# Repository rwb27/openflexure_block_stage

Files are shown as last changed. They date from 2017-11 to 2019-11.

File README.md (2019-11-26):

# This repository has moved!
Please head to our new home on Gitlab: https://gitlab.com/openflexure/openflexure-block-stage/

# OpenFlexure Block Stage
A 3D Printable high-precision 3 axis translation stage.

This project is a 3D printable design that enables very fine (sub-micron) mechanical positioning of a small moving stage, with surprisingly good mechanical stability.  It follows on from the [OpenFlexure Microscope](https://github.com/rwb27/openflexure_microscope) which is discussed in a [paper in Review of Scientific Instruments](http://dx.doi.org/10.1063/1.4941068) (open access).  Currently, it's designed to function as a more-or-less drop in replacement for fibre alignment stages available from various scientific suppliers, but the project aims to be useful to electrophysiologists, nanotechnology folk, and many more.

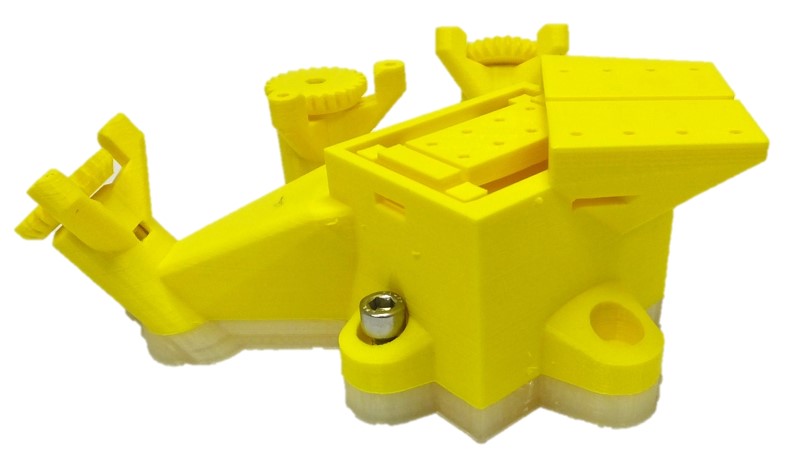
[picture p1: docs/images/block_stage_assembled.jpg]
An assembled block stage


## Kits and License
This project is open-source and is released under the CERN open hardware license.  You can buy a kit of the openflexure microscope from [WaterScope](http://www.waterscope.org/).  Currently, only microscope kits are listed, but if you send an email it should be possible to get this stage as a custom order.

## Printing/building it yourself
To build the stage, download the [STL files](./stl/) and print them.  Don't just print everything from the STL folder,
as currently it contains some parts that must be printed multiple times, and other parts
that are redundant.  The readme in that folder should point you in the right direction.

Instructions for this stage are currently work-in-progress.  However, the assembly of the actuators is exactly the same as for the OpenFlexure Microscope, which has [online instructions](http://rwb27.github.io/openflexure_microscope/docubricks/current_master_version.html).  Instead of separate feet, this design has a single baseplate, which is just glued onto the bottom of the main body of the stage.  Once the actuators are assembled as per those instructions, you just need to mount whatever you're going to translate onto the stage using the 8 M3 "self tapping" holes (tapping them with a tap wrench can help get the screw started).  There's a "moving stage" part that makes it a drop-in replacement for the ThorLabs/Newport XYZ fibre alignment stages, if that is of interest.

## Get Involved
It's already useful if you get involved by raising [issues](https://github.com/rwb27/openflexure_block_stage/issues) if there are things that aren't clear, and anyone who might want to help write better instructions would be very welcome.  Ideally it should be in DocuBricks format, but Markdown/Wiki is a lot better than nothing.  Improvements to the code, or even just sharing parameters you used (if you customised it) and how well it worked would be great.  If you've built one, please post a photo and any comments - you could use the wiki, or [raise an issue tagged "build report"](https://github.com/rwb27/openflexure_block_stage/issues/new?labels=build%20report).

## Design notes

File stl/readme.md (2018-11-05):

# OpenFlexure Block Stage STL Files
This folder is for built STL files.  It's possible I should have excluded these from the repo, as they are build products - but it's often handy to have them here.  *Please don't just print this folder* as there is no guarantee that one of each is the right combination of things to print!

To make one stage, you need:
* 1x stage body (``main_body.stl`` - or optionally the one with ``no_fixed_platform`` or ``long_z_travel``.  Use the ``betweenholes`` version if you want the stage to bolt down to a breadboard with the beam path between two lines of holes (the default is to align it so the beam runs directly along a line of holes).)
* 1x base (``base.stl``) - check this matches up with the top part you've chosen (the top of this should match the bottom of the stage - they just glue together).
* 3x ``large_gear.stl`` to actuate the three axes
* 1x moving platform (``moving_platform.stl``) if you would like drop-in compatibility with standard fibre alignment stages.

If you are planning to motorise the stage with 28BYJ-48 stepper motors, you'll also need:
* 3x ``small_gear.stl``

In addition to the printed parts, you also need:
* 3x Viton o-rings
* 3x M3 full nut, preferably brass
* 3x M3 hexagon head bolts, 25mm long
* 3x M3 washer

If you are building a motorised stage, you also need
* 3x 28BYJ-48 stepper motors
* 6x M4x6mm screws (I use button head with a hex socket)

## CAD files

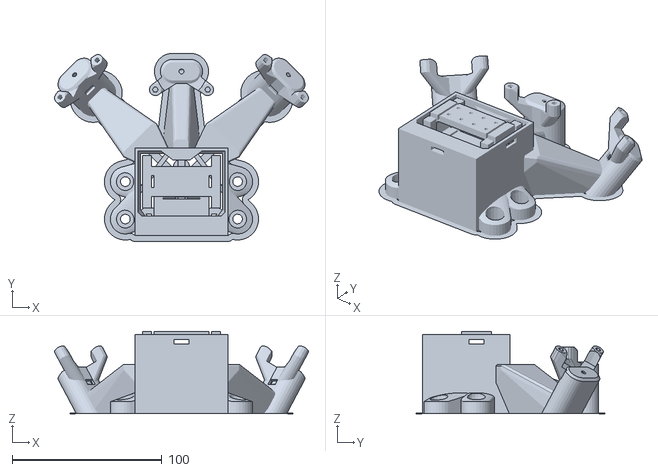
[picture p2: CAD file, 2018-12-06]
stl/main_body_brim.stl
169.7 x 125.8 x 55.0

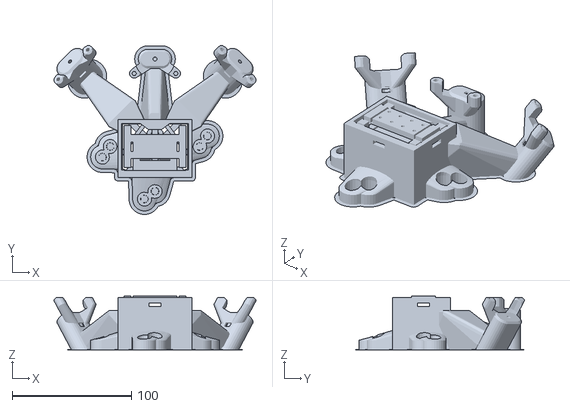
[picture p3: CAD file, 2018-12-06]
stl/main_body_3mmbrim.stl
169.7 x 141.8 x 45.0

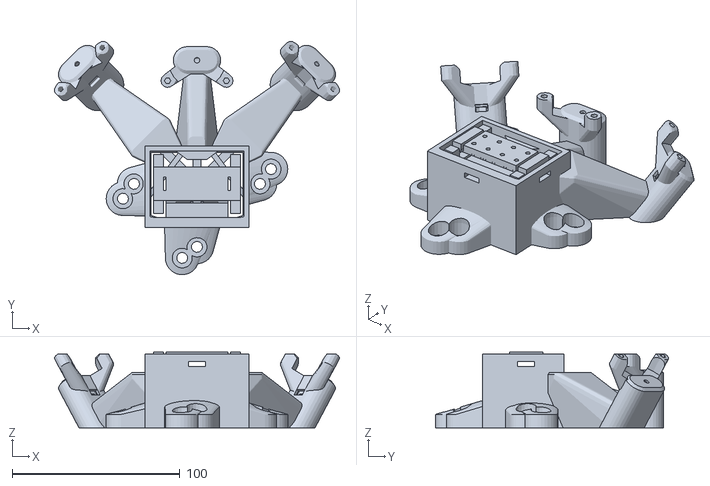
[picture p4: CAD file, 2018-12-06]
stl/main_body.stl
169.7 x 138.8 x 45.0

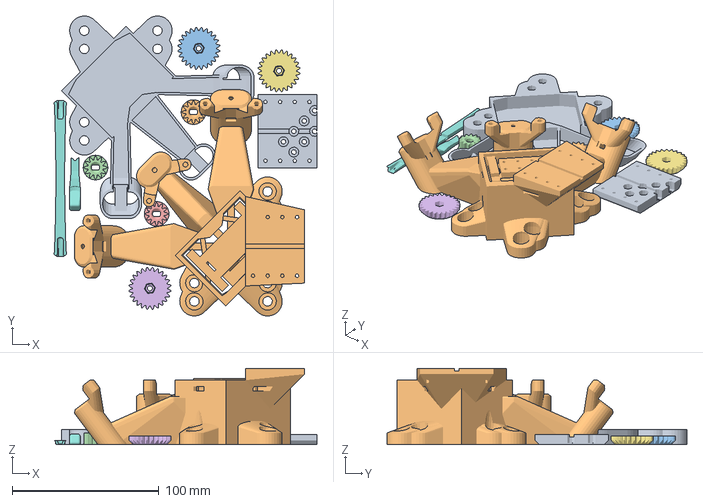
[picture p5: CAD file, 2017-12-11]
stl/1_fs_complete_betweenholes.curaproject.3mf
178.9 x 204.3 x 52.0 mm

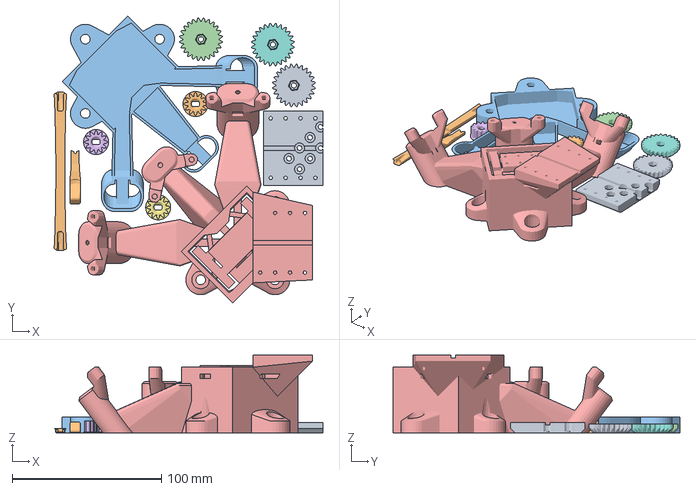
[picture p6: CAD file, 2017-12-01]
stl/1_fs_complete_aligned.3mf
180.3 x 192.6 x 52.0 mm

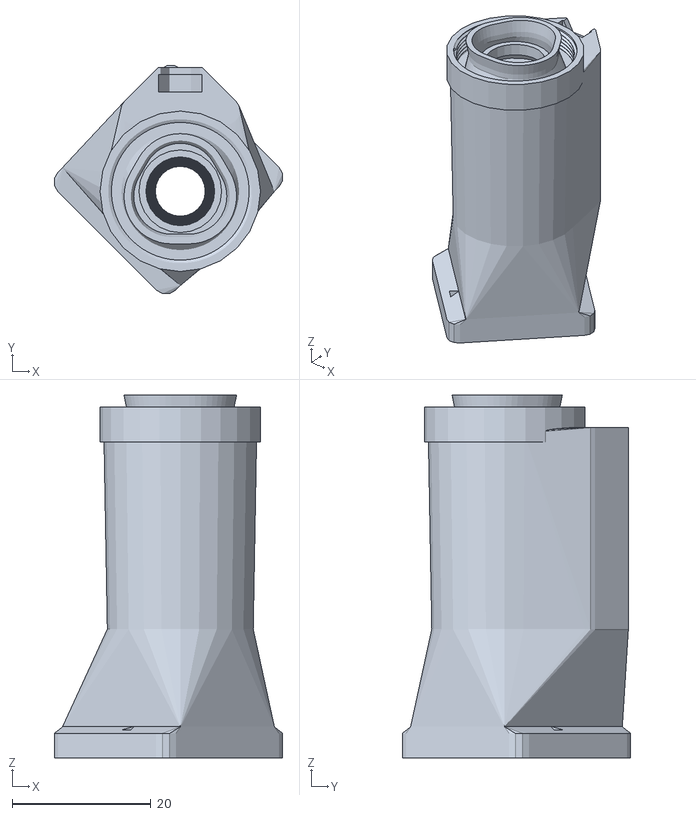
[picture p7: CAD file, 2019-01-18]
openscad/accessories/optics_module_rms_f50d13_infiniteconjugates.stl
32.9 x 32.9 x 52.3

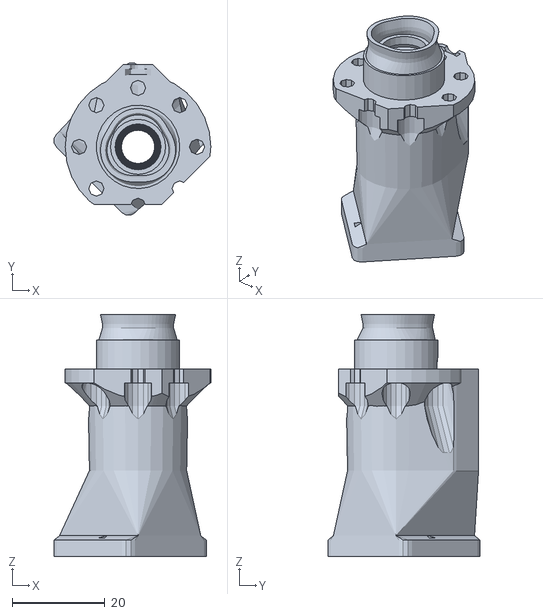
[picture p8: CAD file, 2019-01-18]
stl/accessories/microscope_module_infiniteconjugates.stl
33.9 x 32.9 x 52.3

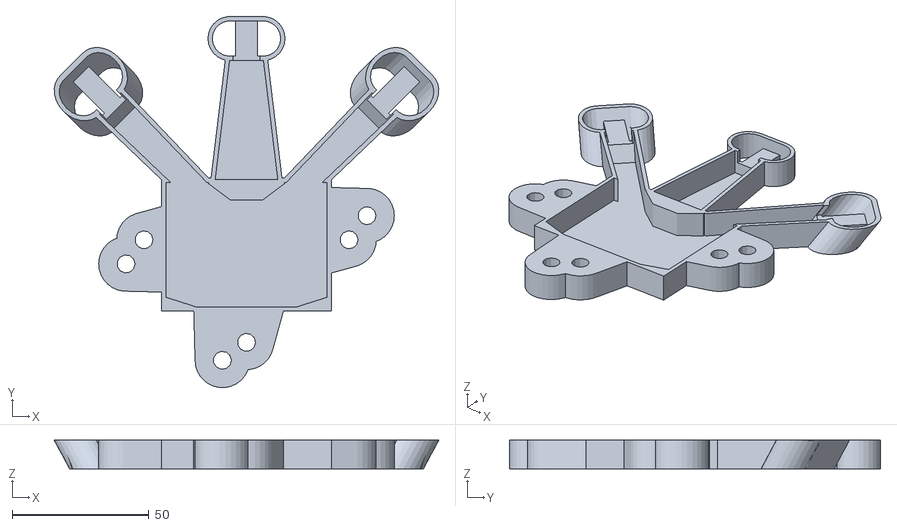
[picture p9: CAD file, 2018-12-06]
stl/base_lugsatsides.stl
140.6 x 135.7 x 10.5

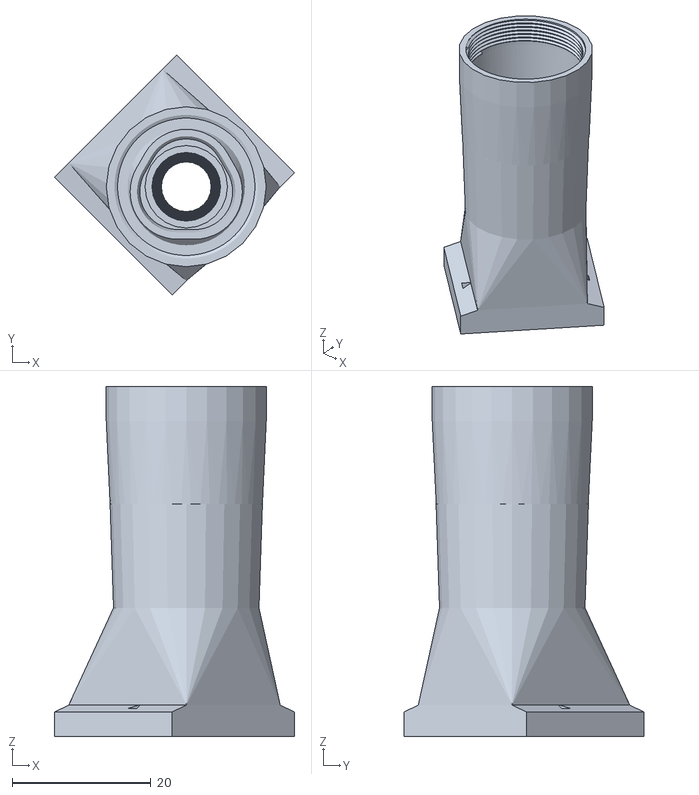
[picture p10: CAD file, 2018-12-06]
openscad/accessories/optics_module_rms_f50d13_nodovetail.stl
34.6 x 34.6 x 50.5

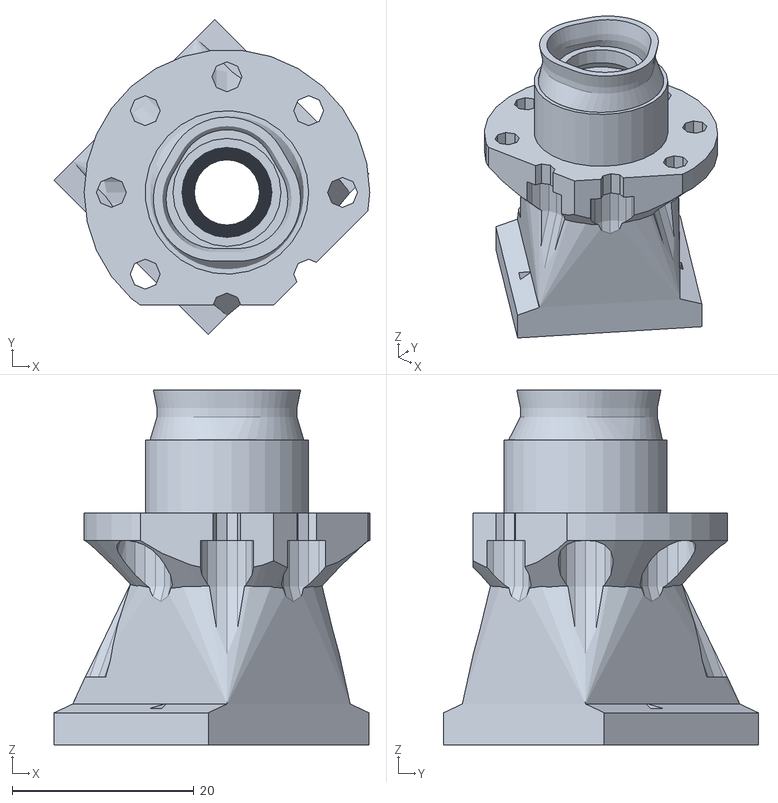
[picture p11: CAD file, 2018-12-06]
stl/accessories/microscope_module_25mm.stl
34.7 x 34.6 x 39.1

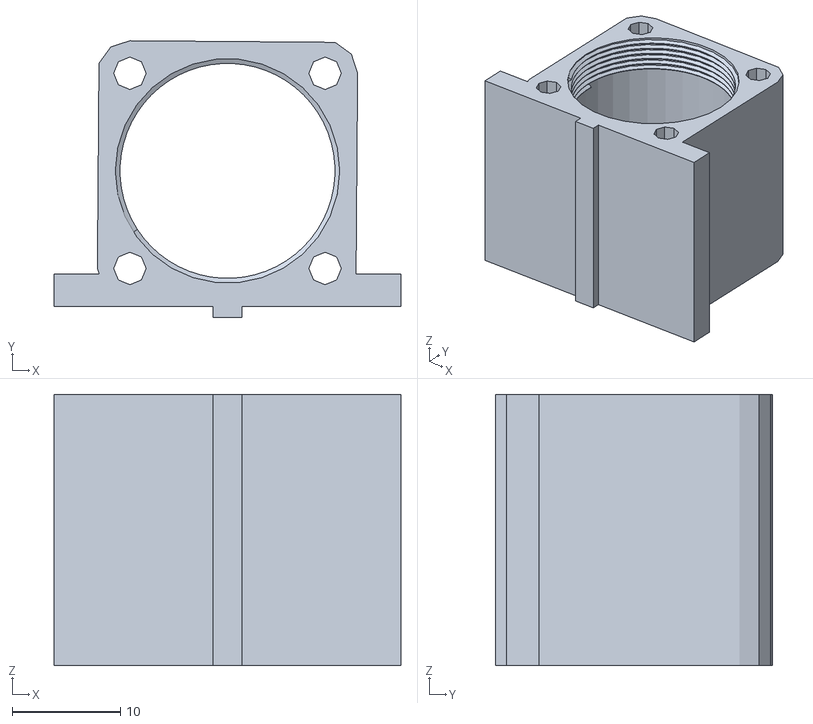
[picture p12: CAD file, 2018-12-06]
stl/accessories/rms_to_stage_25mm.stl
32.0 x 25.5 x 25.0

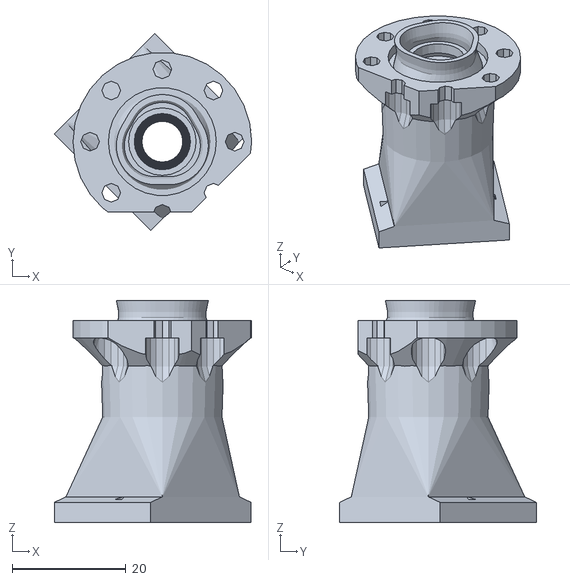
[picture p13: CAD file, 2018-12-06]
stl/accessories/microscope_module_15mm.stl
34.7 x 34.6 x 39.1

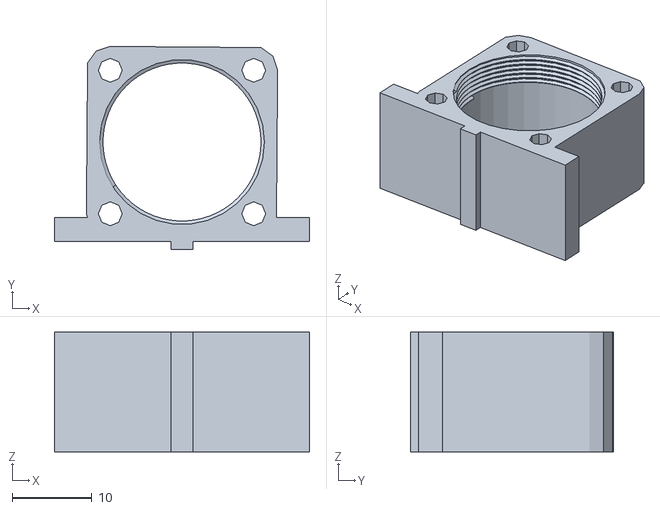
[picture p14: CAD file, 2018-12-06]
stl/accessories/rms_to_stage_15mm.stl
32.0 x 25.5 x 15.0

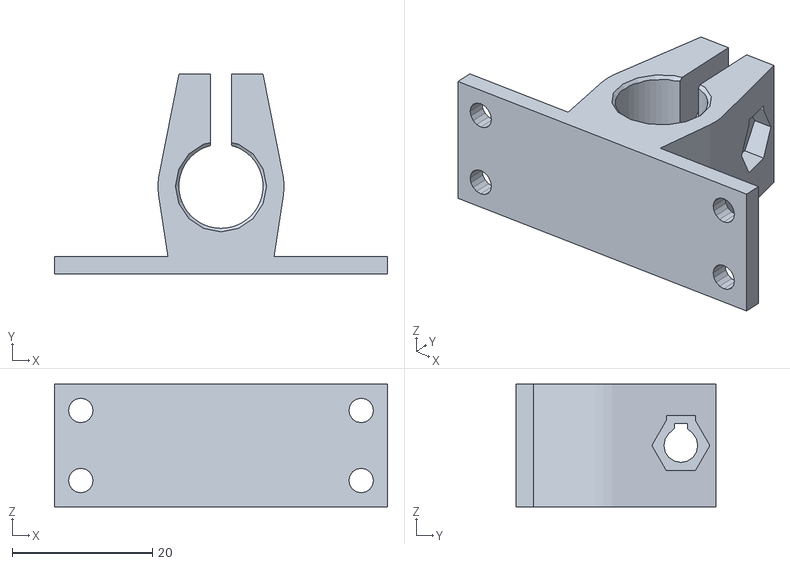
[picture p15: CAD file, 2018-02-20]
stl/accessories/CPS532_to_microblock.stl
47.5 x 28.5 x 17.5

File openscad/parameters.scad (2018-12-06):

/*
  Useful settings/parameters for the OpenFlexure fibre stage
*/
version_numstring = "0.2.1";
stage = [37,20,5]; // dimensions of stage part
beam_height = 75; // height of beam above the table
stage_to_beam_height = 12.5;
stage_height = beam_height - stage_to_beam_height; //bottom of base to top surface of the stage 
 // NB platform_z sets the distance from bottom of the body to top of the stage
 // stage_height determines the thickness of the base.
brim_r = 0;

// Range of travel is lever length * flex_a
xy_lever = 10;
z_lever = 10;

// Mechanical reduction settings
xy_stage_reduction = 30/xy_lever; //ratio of sample motion to lower shelf motion
xy_reduction = 50/xy_lever; //mechanical reduction from screw to sample
z_reduction = 50/z_lever; //mechanical reduction for Z

// Motor lugs
motor_lugs = true;

// fixed platform for fibre launch
fixed_platform = false;

// Mounting holes
breadboard_lugs="diagonal"; //sets the hole pattern for bolting it down.  See the options below.

// Flexure dimensions - good for PLA and ~0.5mm nozzle
zflex = [6, 1.5, 0.75]; //dimensions of flexure
xflex = [5,5.5,5]; //default bounding box of x flexure
xflex_t = 1; //thickness of bendy bit in x
flex_a = 0.1; //angle through which flexures are bent, radians
dz = 0.5; //thickness before a bridge is printable-on

xy_travel = xy_lever * flex_a; //max. travel in X or Y
xy_bottom_travel = xy_travel * xy_stage_reduction; //travel of bottom of XY stage
xy_actuator_pivot_w = 25; //width of the hinge for the actuating lever
actuator_h = 26; //height of actuator columns (~screw length)

pushstick = [5,38,5]; //cross-section of XY "push stick"
pw = pushstick[0]; //because this is used in a lot of places...

wall_t = 1.6;
d=0.05;

// Height of the bridging "shelves" in the XY axis "table" structure
shelf_z1 = xy_lever * xy_stage_reduction;
shelf_z2 = shelf_z1 + xy_lever;

// Z axis geometry
z_travel = z_lever * flex_a; //max. travel in Z
z_stage_base_y = -stage[1]/2-xy_bottom_travel; //position of the flexure edge of the Z stage
z_stage_base_w = stage[0] + 2*zflex[1] - 2*xy_bottom_travel - 2; //width of the flexure edge of the Z stage
z_anchor_bottom_y = z_stage_base_y - z_lever - zflex[1]; // lower Z stage end of the fixed base
z_actuator_pivot_y = stage[1]/2 + zflex[1] + zflex[0] + xy_bottom_travel + wall_t;
z_actuator_pivot_w = 20; //width of the hinge for the Z actuator lever
z_pushstick_z = shelf_z1 - pw - 2.5; // height of the Z pushstick

// Mounting stuff
// By default, place 3 mounting holes to align the centre of the stage with a hole.
// setting beam_between_holes adds another set of holes, putting the beam halfway between
bolt_spacing = 25; // change to 25.4 for imperial tables
mounting_bolts_alongholes = [[-1,0,0],[0,-1,0],[1,0,0]]*1.5*bolt_spacing; //beam aligned with holes
mounting_bolts_betweenholes = [[-1.25,-0.25,0],[1.25,0.25,0],[-0.25,-1.25,0]]*1.41*bolt_spacing;
mounting_bolts_atsides = [[-1.5,0,0],[1.5,0,0],[-1.5,-1,0],[1.5,-1,0]] * bolt_spacing;
mounting_bolts_diagonal = concat(mounting_bolts_alongholes, 
                                 mounting_bolts_betweenholes);
// I hope you'll excuse the stacked ternaries, this is an unpleasant necessity :(
mounting_bolts = breadboard_lugs=="atsides"?mounting_bolts_sides:
                 breadboard_lugs=="diagonal"?mounting_bolts_diagonal:
                 breadboard_lugs=="alongholes"?mounting_bolts_alongholes:
                 breadboard_lugs=="betweenholes"?mounting_bolts_betweenholes:
                 /*breadboard_lugs=="none"?*/[];
            
platform_z = shelf_z2 + stage[2] + 7; // The platform is a fixed height above the moving stage
fixed_platform_standoff = 10;
fixed_platform = [50,40,4];
platform_gap = xy_travel + 1;
casing_top = shelf_z2 + stage[2] - z_travel; // top of the wall
max_actuator_travel = max(xy_travel*xy_reduction, z_travel*z_reduction); // maximum distance the actuators protrude below the stage
base_height = stage_height - platform_z; // the base takes up any height not use by the body.
if(base_height < max_actuator_travel + 4) echo("WARNING: stage_height is too low, base will not compile properly!");

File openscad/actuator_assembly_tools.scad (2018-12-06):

/*

Tools for assembling the OpenFlexure Microscope v5.16

(c) 2016 Richard Bowman - released under CERN Open Hardware License

*/

use <utilities.scad>;
use <compact_nut_seat.scad>;
include <parameters.scad>;

ns = nut_slot_size();
shaft_d = nut_size()*1.1;
gap = 9; //size of the gap between gear and screw seat
swing_a = 30; //angle through which the tool swings
sso = ss_outer(25); //outer size of screw seat
handle_w = shaft_d+4; //width of the "handle" part
handle_l = sso[0]/2+gap; //length of handle part


module tool_handle(){
    w = handle_w; //width of the handle
    a = swing_a; //angle through which the tool is moved to tighten the nut
    difference(){
        sequential_hull(){
            rotate([-a,0,0]) hull(){
                rc=1.5;
                reflect([1,0,0]) translate([w/2 - rc, rc, rc * tan(45 + a/2)]) sphere(r=rc);
                reflect([1,0,0]) translate([w/2 - rc, rc, gap - rc]) sphere(r=rc);
            }
            translate([-w/2,(gap*cos(a)-ns[2])/tan(a) + gap*sin(a),0]) cube([w,d,ns[2]]);
            //translate([-w/2,ns[2],0]) cube([w,d,ns[2]]);
            translate([-w/2,sso[0]/2*cos(swing_a)+gap*sin(swing_a),0]) cube([w,d,ns[2]]);
            translate([-ns[0]/2,handle_l,0]) cube([ns[0],d,ns[2]]);
        }
        //ground (or bottom of gear)
        mirror([0,0,1]) cylinder(r=999,h=999,$fn=4);
        //screw seat (in swung-in position)
        rotate([0,180-swing_a,-90]) translate([0,0,-(gap+sso[2]/2)]) screw_seat_shell(25);
        //screw
        //rotate([-swing_a,0,0]) cylinder(d=shaft_d,h=999,center=true, $fn=16);
    }
}

module xz_slice(y=0){
    //slice out just the part of something that sits in the XZ plane
    intersection(){
        translate([0,y,0]) cube([9999,2*d,9999],center=true);
        children();
    }
}

module nut_tool(){
    w = ns[0]-0.6; //width of tool tip (needs to fit through the slot that's ns[0] wide
    h = ns[2]-0.7; //height of tool tip (needs to fit through slot)
    l = 5+sso[1]/2+3;
    difference(){
        union(){
            translate([0,-handle_l,0]) tool_handle();
            sequential_hull(){
                xz_slice() translate([0,-handle_l,0]) tool_handle();
                translate([-w/2, 5, 0]) cube([w, d, h]);
                translate([-w/2, l, 0]) cube([w, d, h]);
            }
        }
        
        //nut 
        translate([0,l,-d])rotate(30)cylinder(r=nut_size()*1.15, h=999, $fn=6);
        translate([0,l-nut_size()*1.15+0.4,-d]) cylinder(r=1,h=999,$fn=12);
    }
}

   
module band_tool(){
    w = ns[0]-0.5; //width of tool tip
    h = 4.5; //height of tool tip (needs to fit through slot)
    l = sso[2]/2+foot_height+5;
    // presently, the hook on the actuator is a 1mm radius cylinder, centred
    // 3.5mm from the edge of the (elliptical) wall of the screw seat.
    difference(){
        union(){
            translate([0,-handle_l,0]) tool_handle();
            sequential_hull(){
                xz_slice() translate([0,-handle_l,0]) tool_handle();
                translate([0,l-20,0]) xz_slice() translate([0,-handle_l,0]) tool_handle();
                union(){
                    translate([-3/2, l-12,0]) cube([3,12,h]);
                    translate([-7/2, l-12,h-1]) cube([7,12,1]);
                }
            }
        }
        // cut-out to clear the hook
        hull(){
            translate([0,l,1.5]) scale([1,1,0.66]) rotate([90,0,0]) cylinder(r=1.4,h=18,center=true);
            translate([0,l,2+3]) rotate([90,0,0]) cylinder(r=2.3,h=40,center=true);
        }
        // V shaped end to grip elastic bands
        translate([0,l,0]) hull(){
            translate([0,0.3,1.5]) rotate([0,90,0]) cylinder(r=1,h=999,center=true);
            translate([0,-0.5,h-1.5]) rotate([0,90,0]) cylinder(r=1,h=999,center=true);
        }
        translate([-99,l-0.5,h-1.5]) cube(999);
        // squeeze the sides slightly (commented out for strength)
        reflect([1,0,0]){
//            translate([-7/2,l,h/2-0.3]) rotate([90,15,-3]) scale([1.1,1.5,1]) cylinder(r=1,h=999,center=true);
        }
    }
}

band_tool_l = sso[2]/2+foot_height;
band_tool_w = ns[0]-0.5;
band_tool_h = 4;

module prong_frame(){
    //Move the prongs out and tilt them slightly
    smatrix(xz=0.3, xt=1.9, yt=band_tool_l) children();
}

blade_anchor = [0,-12,0]; //position of the bottom of the slot

module blade_point(pos, d1=1.5, d2=1.5, h=d){
    union(){
        translate(blade_anchor + [0,0,pos[2]]) cylinder(d=d1, h=h);
        translate(pos) cylinder(d=d2, h=h);
    }
}

module band_tool_2(handle=true){
    //forked tool to insert the elastic band
    h = band_tool_h; //overall height of the band insertion tool
    union(){
        // the two "blades" that support the band either side of the hook
        reflect([1,0,0]) prong_frame() sequential_hull(){
            blade_point([0,1.5,0], h=0.5);
            blade_point([0,0,h-1]);
            blade_point([0.3,0.5,h-d],d2=2.1);
        }
        // the flat bottom that passes between the hook and the outside of the column
        hull() reflect([1,0,0]) prong_frame(){ //bottom of the tip
            translate([0,1.5,0]) cylinder(d=1.5,h=0.5);
            translate(blade_anchor) cylinder(d=1.5,h=0.5);
        }
        // connect the business end of the tool to the handle
        difference(){
            hull(){ //join the blades and the handle
                reflect([1,0,0]) prong_frame() translate(blade_anchor) repeat([0,10,0], 2) cylinder(d=1.5,h=h);
                xz_slice() translate([0,-handle_l,0]) tool_handle();
            }
            //cut out to get nice rounded corners at the bottom of the slot for the hook
            hull() reflect([1,0,0]) prong_frame(){
                translate(blade_anchor + [-2.25,3,h]) sphere(r=1.5,h=99);
                translate(blade_anchor + [-1.5,10,0.5]) cube([1.5/2,999,999]);
            }
        }
        //the handle
        if(handle){
            translate([0,-handle_l,0]) tool_handle();
        }
    }
}

module double_ended_band_tool(bent=false){
    roc=2;
    middle_w = 2*column_base_radius()+1.5+2*(band_tool_h-roc)+0.5; //width of the band anchor on the foot
    
    flex_l = roc*3.14/2; //length of the flexible linkers
    
    // We make two tools, spaced out by a flexible joiner
    reflect([0,1,0]) translate([0,middle_w/2+flex_l,0]) if(bent){
        translate([0,roc-3,roc]) rotate([90,0,0]) band_tool_2(handle=false);
    }else{
        band_tool_2(handle=false);
    }
    //flexible links between the two tools and the middle part
    if(bent){
        reflect([0,1,0]) translate([0,middle_w/2,roc]) difference(){
            rotate([0,90,0]) cylinder(r=roc,h=ns[0],center=true);
            rotate([0,90,0]) cylinder(r=roc-0.5,h=99,center=true);
            translate([-99,-99,0]) cube(999);
            translate([-99,-999,-99]) cube(999);
        }
        translate([0,0,0.5/2]) cube([ns[0],middle_w+2*d,0.5],center=true);
    }else{
        translate([0,0,0.5/2]) cube([ns[0],middle_w+2*flex_l+2*d,0.5],center=true);
    }
    //thicker middle part to support the two ends
    hull(){
        translate([0,0,0.5]) cube([ns[0],middle_w,d],center=true);
        translate([0,0,roc]) cube([ns[0],middle_w+2*(roc-0.5),d],center=true);
    }
}

double_ended_band_tool(bent=false);
translate([10,0,0]) nut_tool();

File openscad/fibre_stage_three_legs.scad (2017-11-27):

/*

OpenFlexure Fibre Stage

This project aims to be a high-performance flexure stage, with
short (~2mm) travel and very good accuracy and stability.  It
differs from the microscope by having shorter travel and more
mechanical reduction.  It also has all three axes combined on
one moving stage, rather than separating XY and Z.

*/
use <utilities.scad>;
use <compact_nut_seat.scad>;
include <parameters.scad>;


module xy_table(){
    // XY table structure (anchors to Z stage)
    // This includes the legs and flexures for the XYZ stage and the
    // bottom part to which the XY actuators connect.
    reflect([1,0,0]) reflect([0,1,0]){
        // legs
        translate([stage[0], stage[1], 0]/2 + [1,1,0]*zflex[1]) cube([1,1,0]*zflex[0] + [0,0,shelf_z2 + stage[2] - 2]);
        
        for(z=[0,shelf_z1, shelf_z2]){
            // bridges between legs
            translate([stage[0]/2+zflex[1],-d,z]){
                cube([zflex[0], zflex[1]+stage[1]/2+2*d, zflex[2]]);
                cube([zflex[0], stage[1]/2+d, stage[2]]);
            }
            //shelves between bridges
            translate([-d,-d,z+2*dz]) cube(stage/2+[0,0,stage[2]/2-2*dz]);
            translate([-d, stage[1]/2-zflex[0], z+dz]) cube([stage[0]/2+zflex[1]+2*d, zflex[0], zflex[2]]);
        }
        translate([-d,-d,0]) cube(stage/2); //bottom sits on z=0
    }
}

module x_flexure(){
    // A flexure that bends along the Z direction, for motion in X
    roc = (xflex[0]-xflex_t)/2;
    difference(){
        translate([0,0,xflex[2]/2]) cube(xflex + [0,2*d,0], center=true);
        
        reflect([1,0,0]) hull() reflect([0,1,0]) reflect([0,0,1]){
            translate(xflex/2 - [0,roc,0]) cylinder(r=roc+d, h=999,$fn=16);
        }
    }
}
module xz_flexure(){
    // Two flexures to allow XZ motion of a beam extending along the Y axis
    w = pw;
    h = pushstick[2];
    // Start with an X flexure
    translate([0,xflex[1]/2,0]) x_flexure();
    sequential_hull(){
        translate([0,xflex[1]+w/8,h/2]) cube([w,w/4,h],center=true);
        translate([-w/2,xflex[1]+w/2,0]) cube([w,d,zflex[2]]);
        translate([-w/2,xflex[1]+w/2+zflex[1],0]) cube([w,d,zflex[2]]);
    }
}
module pushstick(){
    // A beam with 2-axis flexures at either end, to constrain 
    // position in 1D
    w = pw;
    h = pushstick[2];
    l = pushstick[1];
    flex_l = xflex[1]+w/2+zflex[1];
    difference(){
        union(){
            repeat([0,l-flex_l,0], 2) xz_flexure();
            translate([-w/2,flex_l,0]) cube([w,l-2*flex_l+d,h]);
        }
        
    }
}
module each_pushstick(){
    // Transformation that creates two pushsticks at 45 degrees
    reflect([1,0,0]) rotate(45) translate([0,pw/2,0]) children();
}

module mechanism_void(){
    //cut-out in the centre of the casing for the mechanism
    difference(){
        sequential_hull(){
            union(){
                cube(stage + [2,2,0]*(xy_bottom_travel + zflex[1] + zflex[0] + 0.5), center=true);
                translate([0,z_stage_base_y-zflex[1]-z_lever+d,0]) 
                        cube([stage[0],2*d,stage[2]*2], center=true);
            }
            translate([0,0,shelf_z1]) union(){
                cube(stage + [2,2,0]*(zflex[1] + zflex[0] + 1.0), center=true); 
                translate([0,-stage[1]/2-zflex[1]-z_lever+d,0]) 
                        cube([stage[0],2*d,d], center=true);
            }
            translate([0,0,shelf_z2]) 
                    cube(stage + [2,2,0]*(zflex[1] + zflex[0] + 1.0 + xy_travel)
                         + [0,0,stage[2]+z_travel*2+6], center=true); 
        }
        
        // take a chunk out to allow for Z actuator reinforcement
       translate([0,z_actuator_pivot_y, 0]) mirror([0,1,0]) hull(){
            w = 2*(z_actuator_pivot_y - pushstick[0]/sqrt(2) - xy_bottom_travel*sqrt(2)) - 1;
            //w = z_actuator_pivot_w;
            translate([-w/2,0,-d]) cube([w, wall_t, shelf_z2]);
            translate([-w/2 + 8,0,-d]) cube([w-8*2, wall_t+6, shelf_z2]);
        }
    }
}
module inter_shelf_spaghetti_slots(){
    // cut outs to clear "spaghetti" from inside of stage
    translate([0,0,shelf_z2-2]) cube([999,10,3],center=true);
    translate([0,0,shelf_z2-2]) cube([10,999,3],center=true);
}

module casing_outline(cubic=true){
    // Once the mechanism void is subtracted, this makes a minimal wall around the structure.
    // NB you need to chop off the top and bottom too.
    if(cubic){
        s = xy_bottom_travel + zflex[1] + zflex[0] + 0.5 + wall_t;
        translate([-stage[0]/2-s, z_anchor_bottom_y-wall_t, 0])
                cube(stage + [2*s,s + (-z_anchor_bottom_y-stage[1]/2) + wall_t,shelf_z2]);
    }else{
        minkowski(){
            hull() mechanism_void();
            cylinder(r=wall_t, h=d, center=true, $fn=8);
        }
    }
}
module casing_outline_top(){
    // 2D object for the top of the casing
    projection(cut=true) translate([0,0,-casing_top + d]) difference(){
        casing_outline();
        mechanism_void();
    }
}

module fixed_platform(){
    // fixed platform to mount objectives, etc.
    so = fixed_platform_standoff;
    difference(){
        hull(){
            //"shelf" part overhanging the edge
            rotate(-135) translate([0,so,platform_z]) mirror([0,0,1]){
                translate([-fixed_platform[0]/2,0,0]) cube(fixed_platform);
                translate([-d,0,0]) cube([2*d, d, fixed_platform[1]+fixed_platform[2]]);
            }
            //"bridge" part 
            translate([0,0,casing_top-d]) 
                    linear_extrude(platform_z-casing_top+d)
                    intersection(){
                        casing_outline_top();
                        rotate(-135) translate([-999,so]) square(999*2);
                    }
        }
        mechanism_void();
        //alignment groove (compatible with standard objective mounts)
        translate([0,0,platform_z]) rotate(-135) cube([3,999,1.7*2],center=true);
        //mounting holes (compatible with standard mounts)
        difference(){
            // NB we leave the bottom closed if it's over the void
            // to avoid messing up the bridge
            rotate(-135) translate([0,so+5,platform_z]) 
                repeat([40,0,0],2,center=true)
                repeat([0,10,0],10) cylinder(r=3/2*0.9,h=20,center=true);
            translate([0,0,0.5]) mechanism_void();
        }
        inter_shelf_spaghetti_slots(); //access ports for print clean-up
    }
}
//fixed_platform();

module moving_platform(){
    // extension to the stage to make it bigger and match fixed platform
    // (not finished)
    stage_top = shelf_z2 + stage[2];
    h = platform_z - stage_top;
    so = fixed_platform_standoff;
    start_y = -so+xy_travel*sqrt(2);
    p = fixed_platform;
    dr = h - p[2]; //amount to move in from top to bottom, for the overhanging sides.
    echo("Platform height is", platform_z);
    difference(){
        hull(){
            //top of the platform
            rotate(45) translate([-p[0]/2,start_y,platform_z - p[2]]) cube(p);
            //bottom of the platform (with 45 degree overhang)
            rotate(45) translate([-p[0]/2+dr,start_y,stage_top]) cube(p-[2,1,0]*dr);
        }
        //alignment groove (compatible with standard objective mounts)
        translate([0,0,platform_z]) rotate(-135) cube([3,999,1.7*2],center=true);
        //mounting holes (compatible with standard mounts)
        // NB we leave the bottom closed if it's over the void
        // to avoid messing up the bridge
        rotate(45) translate([0,start_y+5,platform_z]) 
            repeat([40,0,0],2,center=true)
            repeat([0,10,0],10) cylinder(r=3/2*0.9,h=20,center=true);
        
        //mounting holes in the moving stage
        translate([0,0,stage_top + 1])
            repeat([10,0,0],4,center=true)
            repeat([0,10,0],2,center=true){
                cylinder(d=3*1.15,h=999, center=true);
                cylinder(d=2*3*1.15,h=999);
        }
    }
            
        
}
//moving_platform();
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

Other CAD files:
stl/2_fs_body_universal.curaproject.3mf
stl/accessories/vertical_sample_clips.stl
stl/2_fs_body_aligned.curaproject.3mf
stl/accessories/LED_to_microblock.stl
openscad/base.scad
openscad/accessories/CPS532_to_microblock.scad
openscad/accessories/CPS532_to_top_plate.scad
openscad/accessories/LED_to_microblock.scad
openscad/accessories/LED_to_top_plate.scad
openscad/accessories/cylinder_clamp.scad
openscad/accessories/dovetail.scad
openscad/accessories/microscope_module.scad
openscad/accessories/microscope_module_infiniteconjugates.scad
openscad/accessories/optics_mounts.scad
openscad/accessories/picamera_shim.scad
openscad/accessories/rms_to_top_plate.scad
openscad/accessories/thorlabs_threads.scad
openscad/accessories/vertical_sample_clips.scad
openscad/compact_nut_seat.scad
openscad/gears.scad
openscad/main_body.scad
openscad/moving_platform.scad
openscad/small_gears.scad
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

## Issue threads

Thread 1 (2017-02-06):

Static stage fouls mounting bolts

rwb27, 2017-02-06:
When the static stage is on, it fouls the M6 mounting screws.

rwb27, 2017-02-06:
Fix: reduce the size of the support for the stage and/or make cut-outs for screw insertion.

rwb27, 2017-10-02:
This is now fixed - the static stage tapers to provide clearance for the mounting bolts.

Closed 2017-10-02.

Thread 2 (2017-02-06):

Moving stage needs to match static stage

rwb27, 2017-02-06:
Need to reproduce the static stage on the moving stage (or make a printable adapter)

rwb27, 2017-10-02:
Added a moving platform in 0d1c76816a34bd86c65e945d8aa65b08286b7dae

Closed 2017-10-02.

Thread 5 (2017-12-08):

"self tapping" M3 holes on the platforms strip easily

rwb27, 2017-12-08:
It would be good to update these with the ridged or triangulated holes that are used elsewhere in open flexure stuff...

rwb27, 2019-11-26:
Julian's fixed this in the new repo https://gitlab.com/openflexure/openflexure-block-stage/

Closed 2019-11-26.

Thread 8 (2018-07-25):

Separate feet would be easier for band insertion

rwb27, 2018-07-25:
I could re-use the feet from the microscope to make it easier to fit the elastic bands in.

rwb27, 2019-11-26:
now migradted to https://gitlab.com/openflexure/openflexure-block-stage/

Closed 2019-11-26.

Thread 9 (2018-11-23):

Screw holes incorrect sizes

julianstirling, 2018-11-23:
The holes on the moving platform which should be M3 clearance are hexagonal with a size of 3*1.15mm, the inscribed circle is 2.99mm. Even a close fit M3 clearance is specced as 3.2mm. This is causing a number of stages to self-tap both the platform and the xyz-table, leaving the platform raised or wobbly. This can be fixed with a drill or a knife but would be best to increase the size of $fn in openscad.

rwb27, 2019-11-26:
I think you've fixed this in the new repository https://gitlab.com/openflexure/openflexure-block-stage/

Closed 2019-11-26.

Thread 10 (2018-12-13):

Difficulty in inserting viton band due to poor printing

orisapir, 2018-12-13:
Got the stage printed with a lowish quality printer. This is causing the clearance between the horn and the sides to be small and inconsistent so very difficult to get the viton bands through.
Perhaps a narrower insertion tool can help (beyond better print job)

rwb27, 2019-11-26:
This has now migrated to https://gitlab.com/openflexure/openflexure-block-stage/

Closed 2019-11-26.

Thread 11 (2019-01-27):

Moving platform not in stl folder

julianstirling, 2019-01-27:
The last version where I can find the moving stage stl in the stl folder is:

```
commit a483b23867666ced6fbd4fc924379f1844d74ab3
Author: Richard Bowman <richard.bowman@cantab.net>
Date:   Mon Nov 5 09:33:21 2018 +0000

    Added a note about "betweenholes" versions
```

morgatron, 2019-09-03:
Is the moving_stage STL from the previous version compatible with the rest of the parts from the latest? Or should I just print everything from the previous version?

rwb27, 2019-09-04:
I've not changed anything that would make the old one incompatible, so I'd go ahead and use the previous revision of the moving platform with the latest revision of everything else.

rwb27, 2019-11-26:
This issue should be fixed when we finally sort out CI for the STLs on the new repository on GitLab.  Our new home is: https://gitlab.com/openflexure/openflexure-block-stage/

Closed 2019-11-26.

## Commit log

2017-02-23 Deleted a lot of junk from the microscope
    [12mm_dovetail.stl, 2_microscopes_minus_optics.amf, 4x_body.scad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]
2017-02-23 Merged in improved actuators from microscope
    fixed platform now doesn't obstruct screws
    [compact_nut_seat.scad, fibre_stage_three_legs.scad, fibre_stage_three_legs.stl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]
2017-03-17 Compiled version without fixed platform
    [compact_nut_seat.scad, fibre_stage_three_legs.scad, fibre_stage_three_legs_long_z_travel.stl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]
2017-04-06 updated 3-legged fibre stage with fixed platform
    [fibre_stage_three_legs.scad, fibre_stage_three_legs.stl]
2017-04-12 Upgraded to rounded-edge band slots
    Slots for elastic bands now have rounded edges, to make it easier to
    insert Viton o rings.
    [compact_nut_seat.scad, fibre_stage_three_legs.scad, fibre_stage_three_legs_base.stl]
2017-04-20 Added moving platform
    There's now a moving platform adapter that fits on the moving stage,
    making it a drop-in replacement for a normal fibre stage. Needs a 1.5mm
    shim to get 75mm beam height, could integrate that easily enough.
    [fibre_stage_moving_platform.stl, fibre_stage_three_legs.scad]
2017-10-02 Updated actuator columns (again)
    now matches master branch of openflexure microscope, with easier-to-insert elastic bands.
    [base.scad, compact_nut_seat.scad, fibre_stage_moving_platform.stl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]
2017-10-03 Tidied up some files and updated readme
    [fibre_holder_piscope.stl, fibre_stage_optics_mount.stl]
2017-10-03 Updated base to use new nut seats
    The nut seat was updated from openflexure microscope, but the base no longer matched. This is now fixed, as the base uses the modules provided by compact_nut_seat.
    [fibre_stage_three_legs.scad, fibre_stage_three_legs_base.stl]
2017-10-03 Tidied up filenames and reorganised folder structure
    [C270_mount.scad, base.stl, dovetail.scad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]
2017-10-20 Improved testing adapters
    Added a long optics module and shorter adapter to allow an openflexure microscope module to be mounted.
    [openflexure_microscope_adapter.scad, openflexure_microscope_adapter.stl, optics_holder_for_fibre_stage_testing.scad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]
2017-11-24 Added an LED mount
    [2_stages_plus_gears_and_platforms.curaproject.3mf, LED_to_microblock.scad, LED_to_microblock.stl]
2017-11-27 refactored base to separate file, and fixed height
    Stage now has the correct 75mm beam height when used with standard fibre-alignment accessories, i.e. the top of the stage is 62.5mm from the bench.
    [base.scad, fibre_stage_three_legs.scad, parameters.scad]
2017-11-27 Refactored main body out of big file & fixed overlap
    the Z pushstick now has greater overlap with the Z actuator - hopefully this will fix some print issues I've been having.
    [base_betweenholes.stl, fibre_stage_three_legs.scad, main_body.scad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]
2017-11-27 beam_between_holes parameter
    can now switch mounting holes on and off with a parameter. I should probably include several, so you can turn them all off if you want...
    Also recompiled and saved some cura projects.
    [2_fs_body_aligned.curaproject.3mf, 2_fs_body_universal.curaproject.3mf, main_body_betweenholes.stl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]
2017-12-01 Added combined STL for one full stage
    [1_fs_complete_aligned.3mf, fs_aligned_complete.stl]
2017-12-01 New documentation for the fibre stage
    The docs now have a new docubricks XML file, and a new set of images, that show the fibre stage rather than the microscope being assembled.
2017-12-11 Fixed offset hole positions
    The offset holes were 90 degrees out from where they should have been - they moved the stage along the beam, rather than across it!
    [1_fs_complete_betweenholes.curaproject.3mf, base_betweenholes.stl, main_body_betweenholes.stl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]
2018-02-16 Updated no-fixed-platform version
    [main_body.scad, main_body_no_fixed_platform_betweenholes.stl]
2018-02-20 Added an adapter for a laser diode, for demo/test purposes
    [CPS532_to_microblock.scad, CPS532_to_microblock.stl, cylinder_clamp.scad]
2018-05-01 Recompiled with +/-2mm travel rather than 1mm
    [base.stl, base_betweenholes.stl, fs_aligned_complete.stl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]
2018-05-03 Experimented with a "smart brim"
    Adding a brim only to the outside of the shape really helped bed adhesion, and wasn't a pain to remove, because it didn't gum up the mechanism. This is definitely something to work on, and use in the future.
    [main_body.scad, main_body_brim.stl]
2018-07-13 started an RMS adapter
    [openflexure_microscope_adapter.scad]
2018-07-24 Added RMS adapters
    I've added an RMS adapter that fits to the standard top plates. It can also bolt on to a microscope module for position monitoring applications.
    I reset the travel and beam height to the standard values - I should figure out a way to automate this somehow...
    [main_body.scad, main_body.stl, main_body_3mmbrim.stl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]
2018-07-24 updated screw/nut seat code from microscope repo
    [compact_nut_seat.scad]
2018-07-24 First makefile
    I've put together a basic makefile to build everything, but excluded the build products from the github repo for now.
    I've copied in a bunch of stuff from the microscope - I should probably refactor to have a "common" repo somewhere...
    [CPS532_to_top_plate.scad, LED_to_top_plate.scad, actuator_assembly_tools.scad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]
2018-07-25 fixes for the makefile
    corrected the hole patterns on the stages
    [optics_mounts.scad]
2018-12-06 Fixed fibre stage, which was missing the fixed platform
    [main_body.scad, parameters.scad]
2019-01-07 Updated self-tap holes in utilities and added shims
    [picamera_shim.scad, utilities.scad]
2019-01-18 Added an infinite-conjugates microscope adapter
    [microscope_module_infiniteconjugates.scad, microscope_module_infiniteconjugates.stl, optics_module_rms_f50d13_infiniteconjugates.stl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]
